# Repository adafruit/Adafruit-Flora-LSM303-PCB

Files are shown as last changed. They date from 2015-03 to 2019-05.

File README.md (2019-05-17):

# Adafruit Flora LSM303 Sensor PCB
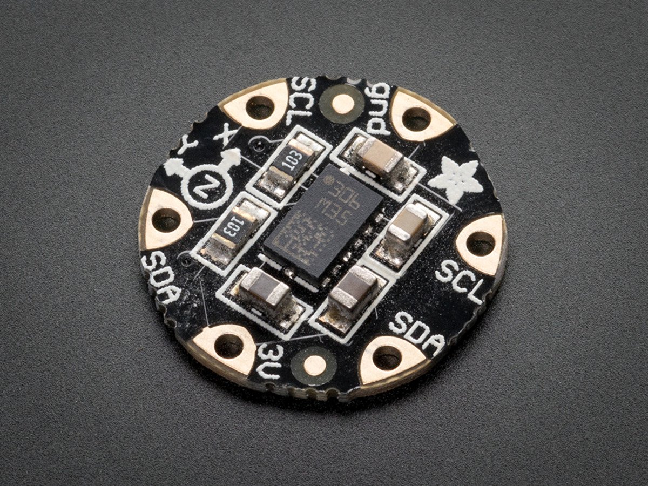
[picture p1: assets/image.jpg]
<a href="http://www.adafruit.com/products/1247"><br/>
Click here to purchase one from the Adafruit shop</a>

Add motion and direction sensing to your wearable FLORA project with this high precision 3-axis Accelerometer+Compass sensor. Inside are two sensors, one is a classic 3-axis accelerometer, which can tell you which direction is down towards the Earth (by measuring gravity) or how fast the board is accelerating in 3D space. The other is a magnetometer that can sense where the strongest magnetic force is coming from, generally used to detect magnetic north. By combining this data you can then orient yourself.

We based this sensor on the latest version of this popular sensor, the LSM303DLHC. The sensor has a digital (I2C) interface. Attaching it to the FLORA is simple: line up the sensor so its adjacent to the SDA/SCL pins and sew conductive thread from the 3V, SDA, SCL and GND pins. They line up perfectly so you will not have any crossed lines. You can only connect one of these sensors to your FLORA, but you can connect other I2C sensors/outputs by using the set of SCL/SDA pins on the opposite side.

PCB files for Adafruit Flora LSM303 sensor. The format is EagleCAD schematic and board layout
- https://www.adafruit.com/product/1247

### License

Adafruit invests time and resources providing this open source design, please support Adafruit and open-source hardware by purchasing products from [Adafruit](https://www.adafruit.com)!

All text above must be included in any redistribution

Designed by Limor Fried/Ladyada for Adafruit Industries.
Creative Commons Attribution/Share-Alike, all text above must be included in any redistribution. 
See license.txt for additional information.

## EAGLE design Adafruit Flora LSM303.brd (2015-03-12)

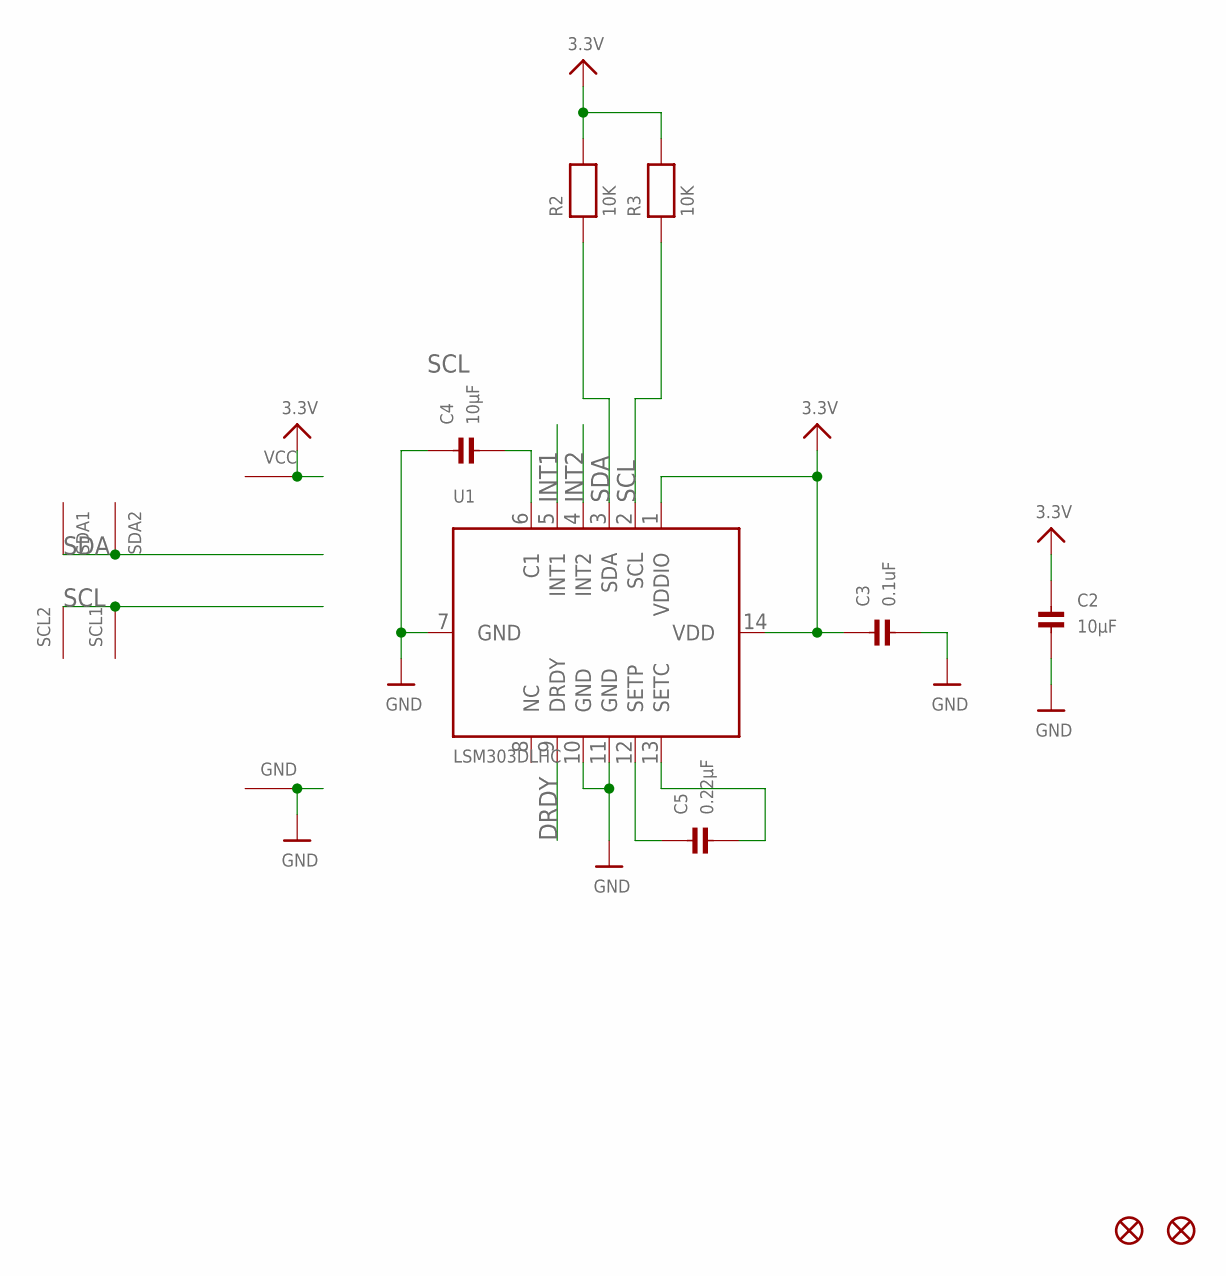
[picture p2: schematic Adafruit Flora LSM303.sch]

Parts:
C2, C4: 10µF; _0805
C3: 0.1uF; _0805
C5: 0.22µF; _0805
FID1, FID2: FIDUCIAL""; FIDUCIAL_1MM
GND: SEWTAP0.5IN; SEWINGTAP_0.5
R2, R3: 10K; _0805
SCL1, SCL2: SEWTAP0.5IN; SEWINGTAP_0.5
SDA1, SDA2: SEWTAP0.5IN; SEWINGTAP_0.5
U1: LSM303DLHC; LGA14
VCC: SEWTAP0.5IN; SEWINGTAP_0.5

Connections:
3.3V: C2.1, C3.1, R2.2, R3.2, U1.1 (VDDIO), U1.14 (VDD), VCC.TAP
DRDY: U1.9 (DRDY)
GND: C2.2, C3.2, C4.1, GND.TAP, U1.7 (GND), U1.10 (GND), U1.11 (GND)
INT1: U1.5 (INT1)
INT2: U1.4 (INT2)
unnamed: C4.2, U1.6 (C1)
unnamed: C5.1, U1.12 (SETP)
unnamed: C5.2, U1.13 (SETC)
SCL: R3.1, SCL1.TAP, SCL2.TAP, U1.2 (SCL)
SDA: R2.1, SDA1.TAP, SDA2.TAP, U1.3 (SDA)

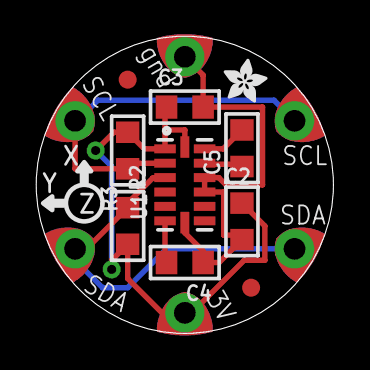
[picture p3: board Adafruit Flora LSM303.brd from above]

Board: 2 copper layers, 16.5 x 16.5 mm, 16 parts (0 on the bottom side), 7 nets.

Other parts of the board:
U$4: ADAFRUIT_2.5MM

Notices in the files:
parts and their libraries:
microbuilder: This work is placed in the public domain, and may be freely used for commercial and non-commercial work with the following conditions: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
